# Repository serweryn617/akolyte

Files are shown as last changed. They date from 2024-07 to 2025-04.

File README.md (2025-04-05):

# Akolyte

⌨️ Low profile mechanical split keyboard

---

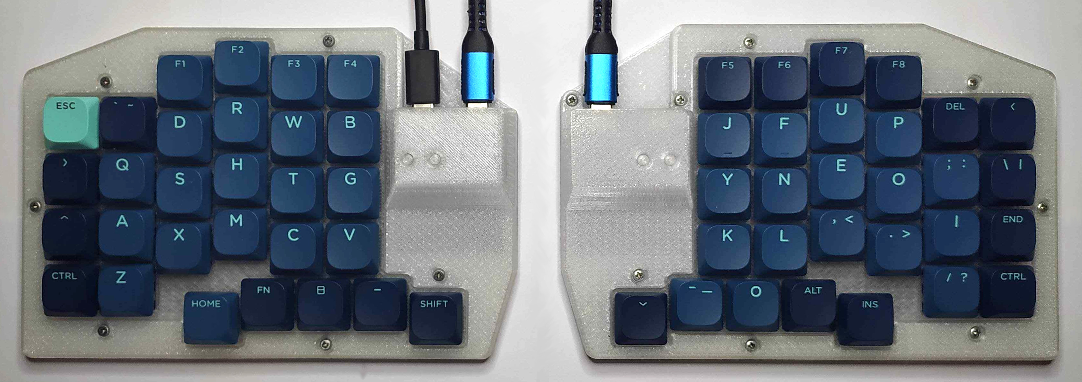
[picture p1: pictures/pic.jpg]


## Building firmware

Prerequisites:
 - `docker`

Firmware can be built using [cook-builder](https://github.com/serweryn617/cook):

**Setup:** initialize submodules and build Docker image. Has to be run only once:

```bash
cook setup
```

**Build:** build everything. Output files will be copied to the `output` directory:

```bash
cook
```

For complete list of commands run `cook -i`.

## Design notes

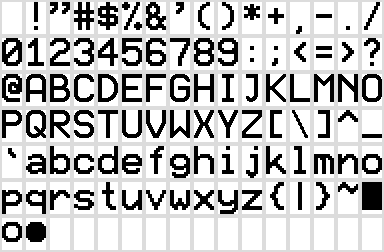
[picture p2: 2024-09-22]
firmware/helpers/chars_32.png

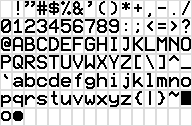
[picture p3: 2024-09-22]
firmware/helpers/chars_16.png

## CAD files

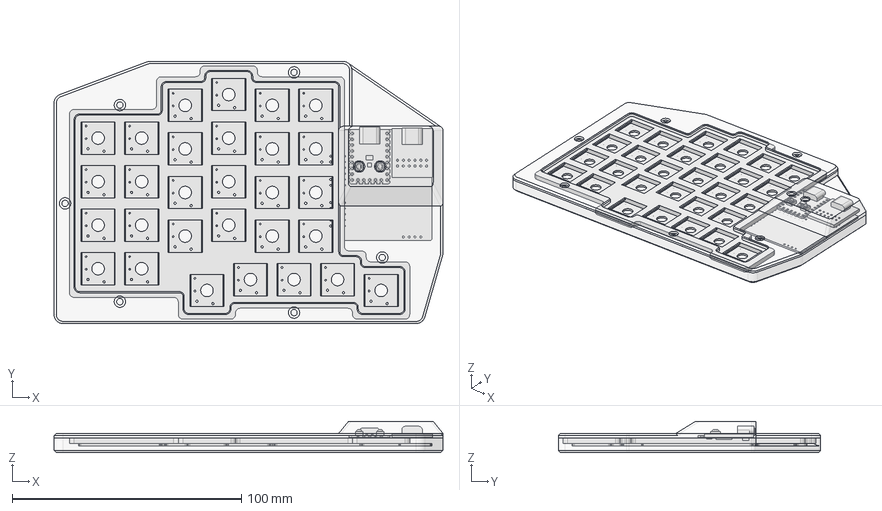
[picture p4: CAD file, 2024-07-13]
cad/freecad/assembly.FCStd
169.8 x 114.5 x 13.6 mm
pcb_left_001
bottom_001
plate_001
rp_001
usbc_001
top_001

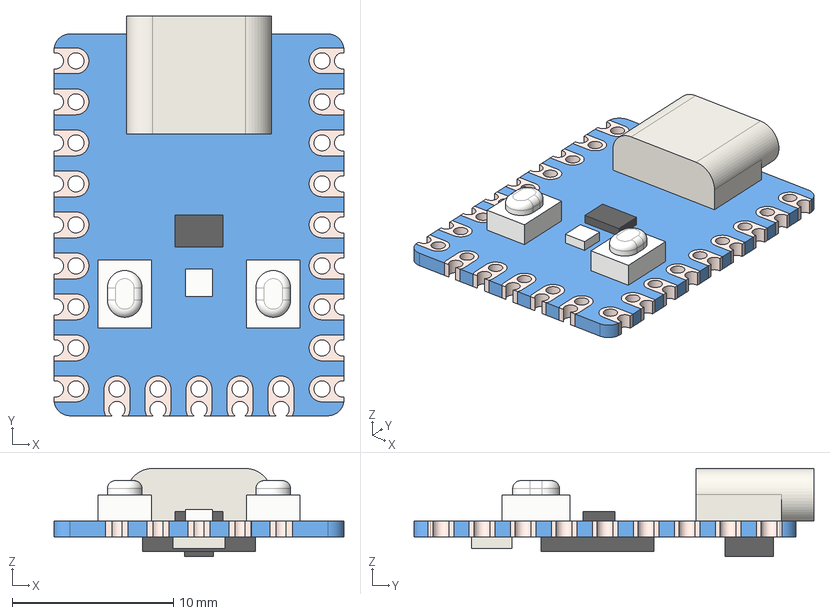
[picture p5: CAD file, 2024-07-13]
cad/freecad/components/rp.FCStd
18.0 x 24.8 x 5.45 mm
RP v1
RP v002
RP v003
RP v004
RP v005
RP v006
RP v007
RP v008
RP v009
RP v010
RP v011
RP v012
RP v013
RP v014
RP v015
RP v016
RP v017
RP v018
RP v019
RP v020
RP v021
RP v022
RP v023
RP v024
RP v025
RP v026
RP v027
RP v028
RP v029
RP v030
RP v031
RP v032

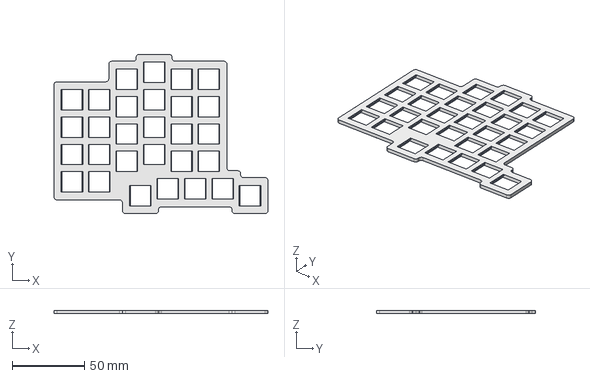
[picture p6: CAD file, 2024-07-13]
cad/freecad/plate.FCStd
148.5 x 110.5 x 2.40 mm

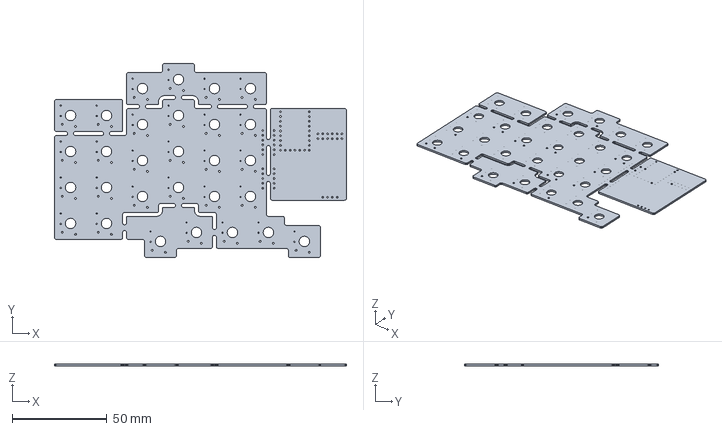
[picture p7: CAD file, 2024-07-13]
cad/freecad/components/pcb_left.FCStd
154.2 x 102.5 x 1.00 mm

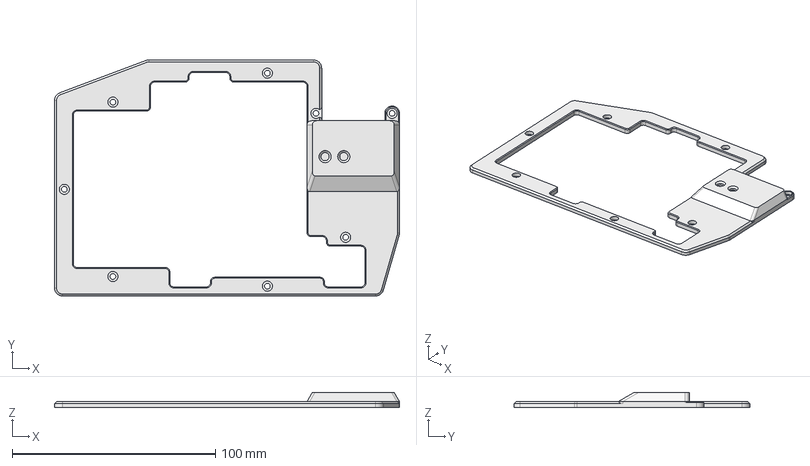
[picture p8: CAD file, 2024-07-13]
cad/freecad/top.FCStd
169.8 x 116.2 x 7.50 mm

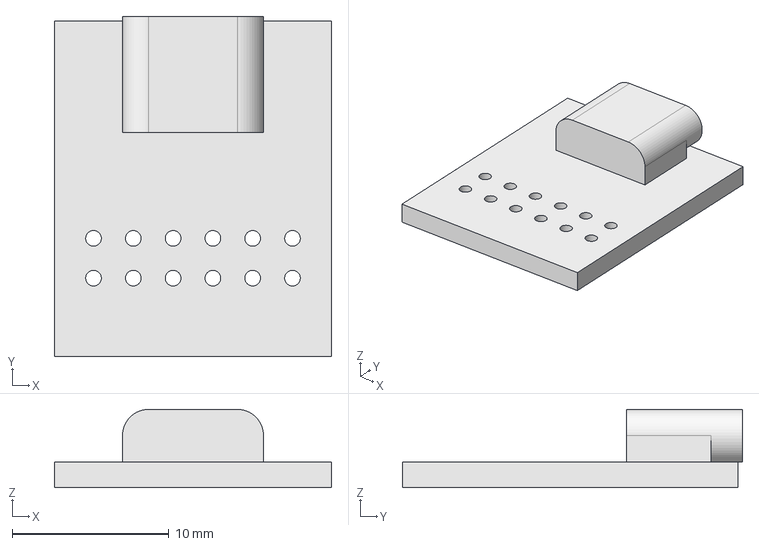
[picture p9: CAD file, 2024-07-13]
cad/freecad/components/usbc.FCStd
17.7 x 21.7 x 5.00 mm

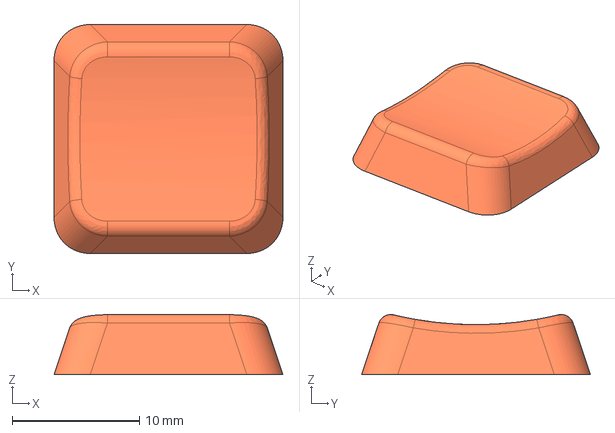
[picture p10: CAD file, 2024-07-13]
cad/freecad/components/keycap.FCStd
18.0 x 18.0 x 4.72 mm

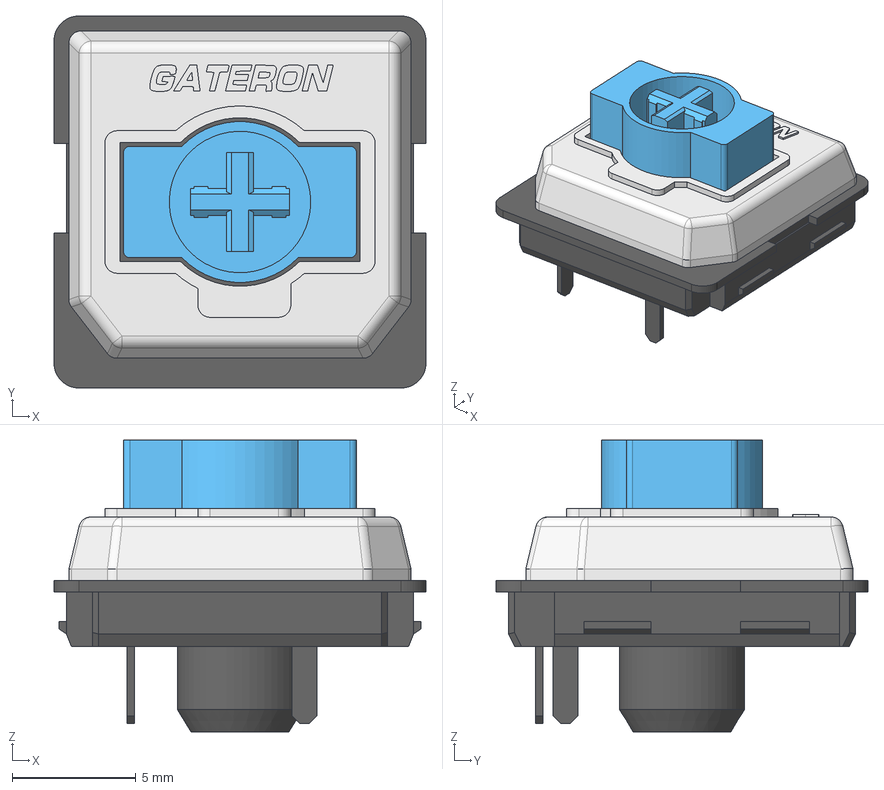
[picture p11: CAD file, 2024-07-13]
cad/freecad/components/gateron.FCStd
15.0 x 15.0 x 11.8 mm
GATERON Low Profile v2
GATERON Low Profile v003
GATERON Low Profile v004

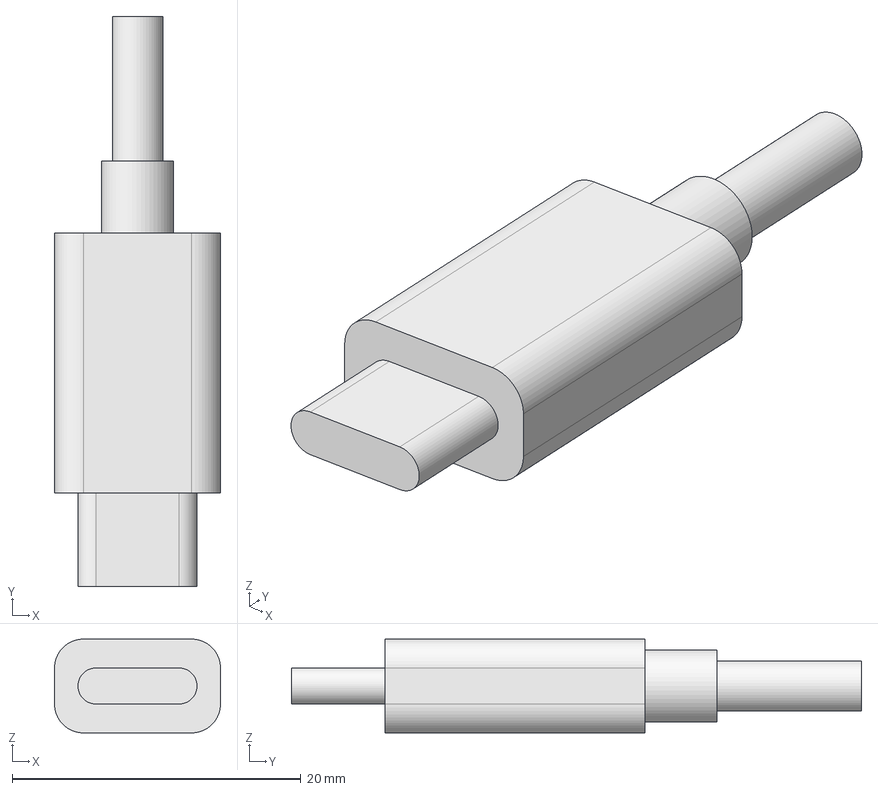
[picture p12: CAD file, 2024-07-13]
cad/freecad/components/usb-plug.FCStd
11.5 x 39.5 x 6.50 mm

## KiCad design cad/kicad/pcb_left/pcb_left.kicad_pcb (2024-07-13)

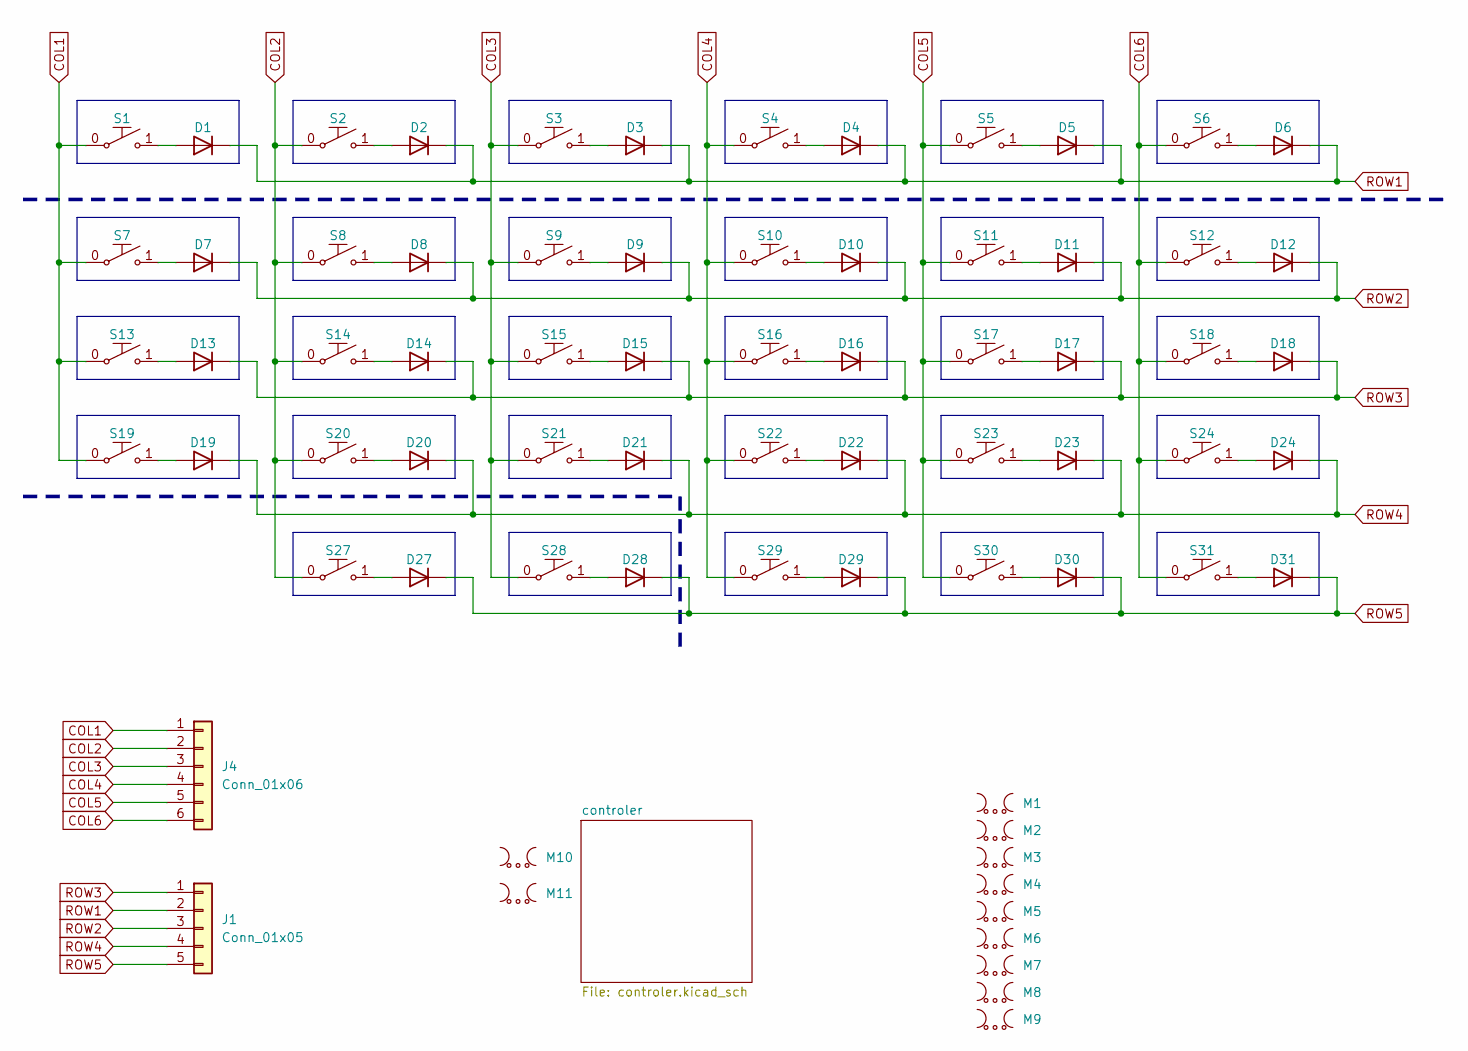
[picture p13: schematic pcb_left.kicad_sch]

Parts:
D1, D2, D3, D4, D5, D6, D7, D8, D9, D10, D11, D12, D13, D14, D15, D16, D17, D18, D19, D20, D21, D22, D23, D24, D27, D28, D29, D30, D31: 1N4148; SOD80_P5.5mm_Horizontal_SMD
J1: Conn_01x05; Row Connector
J4: Conn_01x06; Column Connector
M1, M2, M3, M4, M5, M6, M7, M8, M9, M10, M11: Mouse Bites
S1, S2, S3, S4, S5, S6, S7, S8, S9, S10, S11, S12, S13, S14, S15, S16, S17, S18, S19, S20, S21, S22, S23, S24, S27, S28, S29, S30, S31: Gateron_Switch; GATERON

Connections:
COL1: J4.1, S1.0, S7.0, S13.0, S19.0; also elsewhere on the board
COL2: J4.2, S2.0, S8.0, S14.0, S20.0, S27.0; also elsewhere on the board
COL3: J4.3, S3.0, S9.0, S15.0, S21.0, S28.0; also elsewhere on the board
COL4: J4.4, S4.0, S10.0, S16.0, S22.0, S29.0; also elsewhere on the board
COL5: J4.5, S5.0, S11.0, S17.0, S23.0, S30.0; also elsewhere on the board
COL6: J4.6, S6.0, S12.0, S18.0, S24.0, S31.0; also elsewhere on the board
unnamed: D1.2 (A), S1.1
unnamed: D2.2 (A), S2.1
unnamed: D3.2 (A), S3.1
unnamed: D4.2 (A), S4.1
unnamed: D5.2 (A), S5.1
unnamed: D6.2 (A), S6.1
unnamed: D7.2 (A), S7.1
unnamed: D8.2 (A), S8.1
unnamed: D9.2 (A), S9.1
unnamed: D10.2 (A), S10.1
unnamed: D11.2 (A), S11.1
unnamed: D12.2 (A), S12.1
unnamed: D13.2 (A), S13.1
unnamed: D14.2 (A), S14.1
unnamed: D15.2 (A), S15.1
unnamed: D16.2 (A), S16.1
unnamed: D17.2 (A), S17.1
unnamed: D18.2 (A), S18.1
unnamed: D19.2 (A), S19.1
unnamed: D20.2 (A), S20.1
unnamed: D21.2 (A), S21.1
unnamed: D22.2 (A), S22.1
unnamed: D23.2 (A), S23.1
unnamed: D24.2 (A), S24.1
unnamed: D27.2 (A), S27.1
unnamed: D28.2 (A), S28.1
unnamed: D29.2 (A), S29.1
unnamed: D30.2 (A), S30.1
unnamed: D31.2 (A), S31.1
ROW1: D1.1 (K), D2.1 (K), D3.1 (K), D4.1 (K), D5.1 (K), D6.1 (K), J1.2; also elsewhere on the board
ROW2: D7.1 (K), D8.1 (K), D9.1 (K), D10.1 (K), D11.1 (K), D12.1 (K), J1.3; also elsewhere on the board
ROW3: D13.1 (K), D14.1 (K), D15.1 (K), D16.1 (K), D17.1 (K), D18.1 (K), J1.1; also elsewhere on the board
ROW4: D19.1 (K), D20.1 (K), D21.1 (K), D22.1 (K), D23.1 (K), D24.1 (K), J1.4; also elsewhere on the board
ROW5: D27.1 (K), D28.1 (K), D29.1 (K), D30.1 (K), D31.1 (K), J1.5; also elsewhere on the board

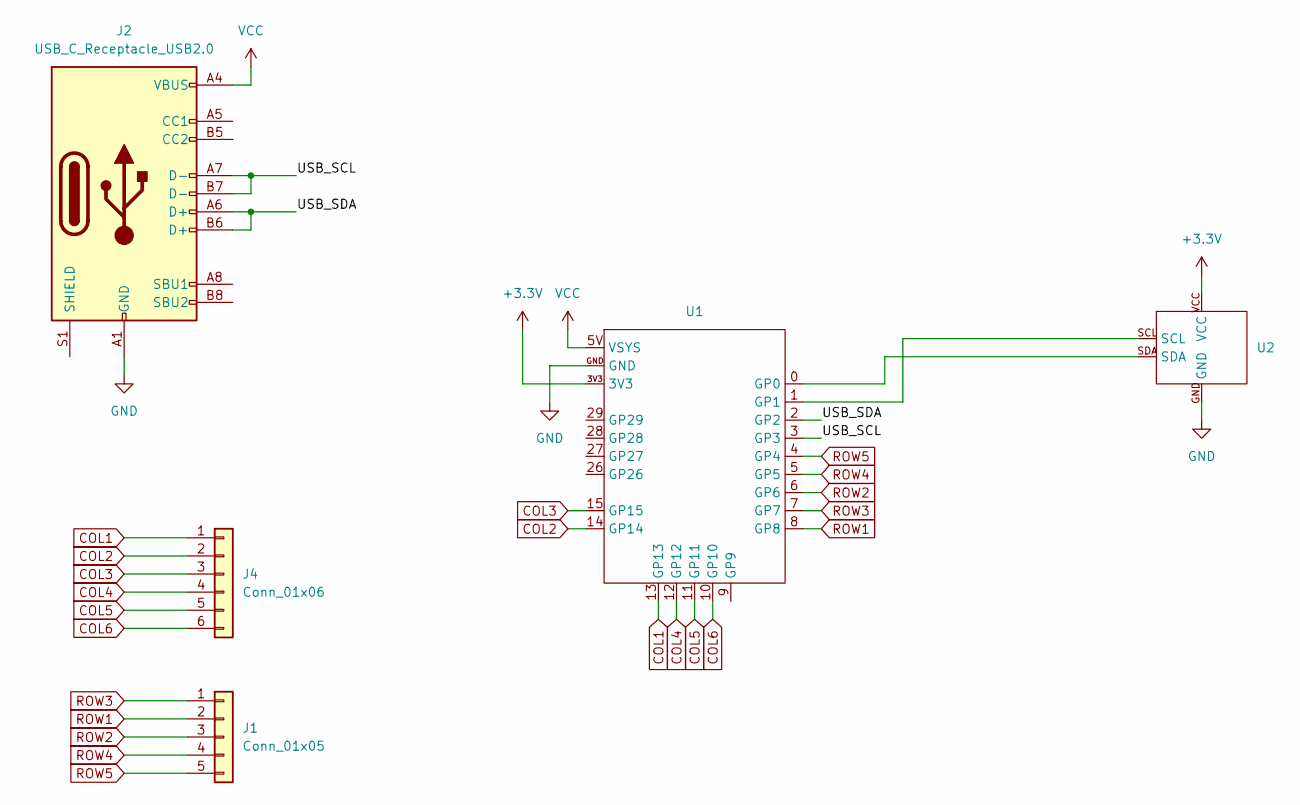
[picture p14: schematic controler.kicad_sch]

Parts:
J1: Conn_01x05; Row Connector
J2: USB_C_Receptacle_USB2.0; USB C Port
J4: Conn_01x06; Column Connector
U1: RP2040 - Zero
U2: OLED

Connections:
+3.3V: U1.3V3, U2.VCC
/controler/USB_SCL: J2.A7 (D-), J2.B7 (D-), U1.3 (GP3)
/controler/USB_SDA: J2.A6 (D+), J2.B6 (D+), U1.2 (GP2)
COL1: J4.1, U1.13 (GP13); also elsewhere on the board
COL2: J4.2, U1.14 (GP14); also elsewhere on the board
COL3: J4.3, U1.15 (GP15); also elsewhere on the board
COL4: J4.4, U1.12 (GP12); also elsewhere on the board
COL5: J4.5, U1.11 (GP11); also elsewhere on the board
COL6: J4.6, U1.10 (GP10); also elsewhere on the board
GND: J2.A1 (GND), J2.A12 (GND), J2.B1 (GND), J2.B12 (GND), U1.GND, U2.GND
unnamed: U1.0 (GP0), U2.SDA
unnamed: U1.1 (GP1), U2.SCL
ROW1: J1.2, U1.8 (GP8); also elsewhere on the board
ROW2: J1.3, U1.6 (GP6); also elsewhere on the board
ROW3: J1.1, U1.7 (GP7); also elsewhere on the board
ROW4: J1.4, U1.5 (GP5); also elsewhere on the board
ROW5: J1.5, U1.4 (GP4); also elsewhere on the board
VCC: J2.A4 (VBUS), J2.A9 (VBUS), J2.B4 (VBUS), J2.B9 (VBUS), U1.5V (VSYS)

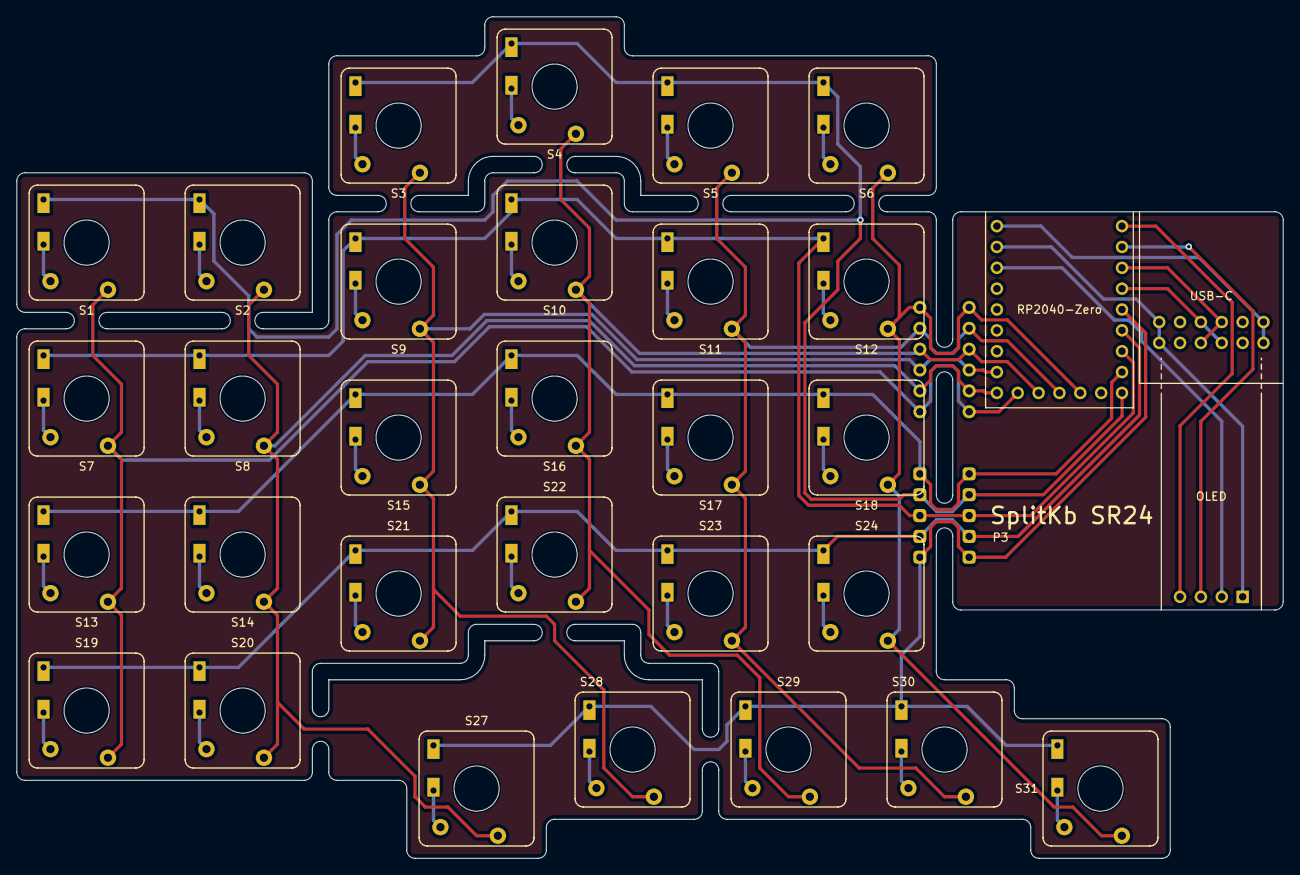
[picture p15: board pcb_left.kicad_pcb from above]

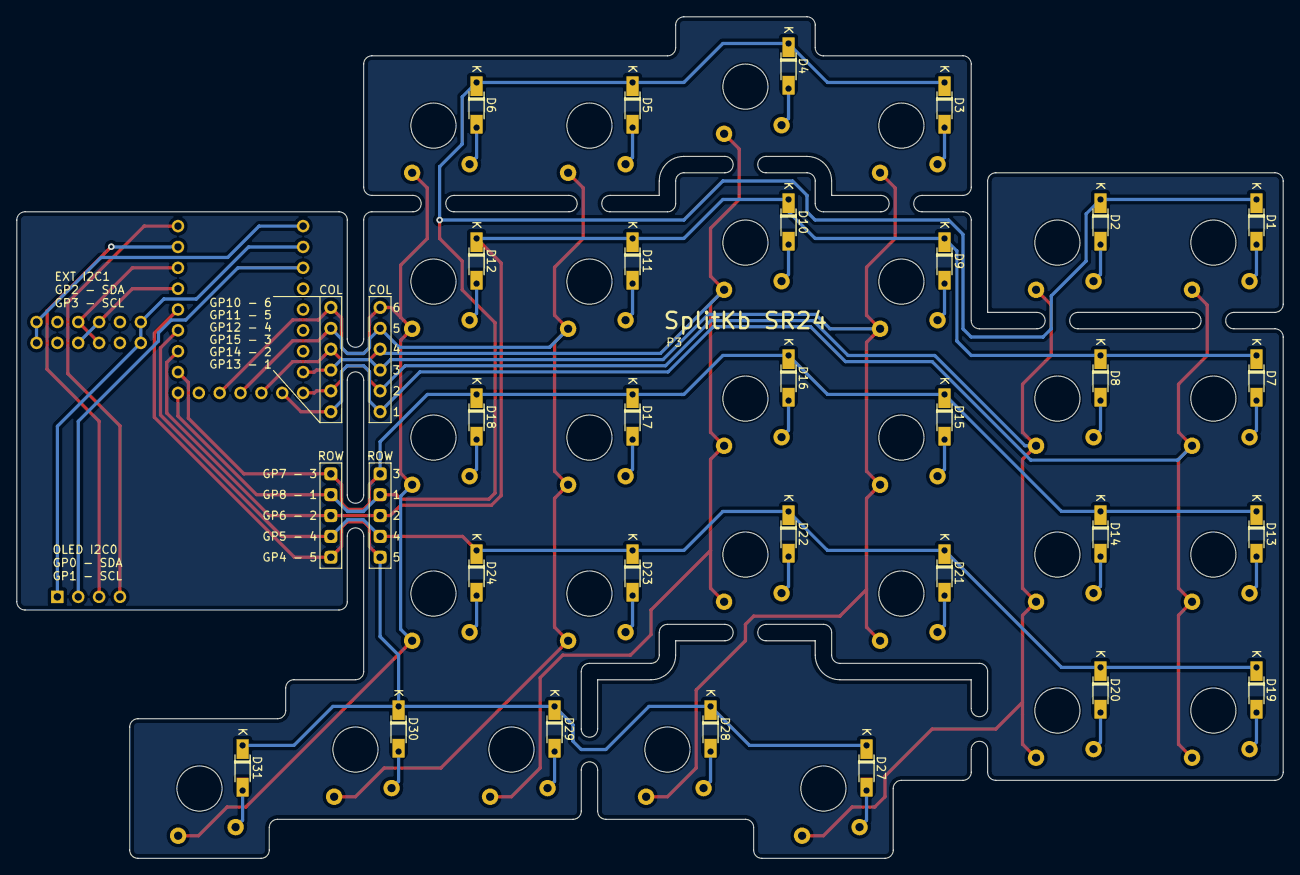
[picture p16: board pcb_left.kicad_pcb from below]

Board: 2 copper layers, 154.2 x 102.5 mm, 76 parts (33 on the bottom side), 47 nets.

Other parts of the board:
J5: Conn_01x06; Column Connector
J6: Conn_01x05; Row Connector

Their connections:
COL1: J5.1; also elsewhere on the board
COL2: J5.2; also elsewhere on the board
COL3: J5.3; also elsewhere on the board
COL4: J5.4; also elsewhere on the board
COL5: J5.5; also elsewhere on the board
COL6: J5.6; also elsewhere on the board
ROW1: J6.2; also elsewhere on the board
ROW2: J6.3; also elsewhere on the board
ROW3: J6.1; also elsewhere on the board
ROW4: J6.4; also elsewhere on the board
ROW5: J6.5; also elsewhere on the board

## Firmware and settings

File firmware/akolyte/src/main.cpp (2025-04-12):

#include "pico/multicore.h"

#include "akolyte/core1.hpp"
#include "akolyte/flow_selector.hpp"
#include "akolyte/i2c_worker.hpp"
#include "akolyte/usb_manager.hpp"
#include "communication/communication.hpp"
#include "defs/defs.hpp"
#include "i2c/i2c_driver.h"
#include "keypad/keypad.hpp"
#include "queue/queue.hpp"
#include "tinyusb.hpp"
#include "types.h"

using namespace drivers::i2c;
using namespace lib::communication;
using namespace lib::keypad;
using namespace lib::queue;

tinyusb_callback global_tinyusb_callback {
    .complete = true,
    .leds = 0,
    .mounted = false,
    .suspended = false,
};

int main()
{
    Queue queue;
    queue.initialize();

    TinyUSB t_usb(global_tinyusb_callback);
    I2CDriver i2c_driver(i2c1, ext_i2c_sda, ext_i2c_scl, 0x55);
    communication comms(i2c_driver);

    Keypad keypad(keypad_in_pins, keypad_out_pins);
    usb_manager manager(t_usb, comms, global_tinyusb_callback, keypad, queue);
    i2c_worker worker(comms, keypad, queue);
    flow_selector selector(t_usb, comms, global_tinyusb_callback, manager, worker);

    if constexpr (config::side == config::left) {
        multicore_launch_core1(core1_main);
    }

    keypad.init_gpio();
    selector.init_all();
    selector.start();
}

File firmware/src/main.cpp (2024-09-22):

#include <stdio.h>

#include "pico/stdlib.h"
#include "pico/multicore.h"
#include "pico/util/queue.h"

#include "pico_i2c_driver.h"
#include "defs.hpp"
#include "keypad.hpp"
#include "led.hpp"
#include "tinyusb.hpp"
#include "types.h"
#include "flow_selector.hpp"
#include "usb_manager.hpp"
#include "i2c_worker.hpp"
#include "logger.hpp"
#include "ssd1306.h"

tinyusb_callback g_tinyusb_callback {
    .complete = true,
    .leds = 0,
    .mounted = false,
    .suspended = false,
};

queue_t inter_core_queue;

void core1_main()
{
    drivers::pico::PicoI2CDriver i2c_driver(oled_i2c, oled_i2c_sda, oled_i2c_scl, oled_i2c_address);
    i2c_driver.init();

    ssd1306 oled(i2c_driver);
    oled.init();

    uint8_t last_message = 0;

    while(true) {
        oled.set_cursor(0, 0);
        switch (last_message) {
            case 0:
                oled.print_string("None");
                break;
            case 1:
                oled.print_string("Running primary");
                break;
            case 2:
                oled.print_string("Running secondary");
                break;
            default:
                oled.print_string("ERROR");
                break;
        }
        oled.display();
        queue_remove_blocking(&inter_core_queue, &last_message);
    }
}

int main()
{
    queue_init(&inter_core_queue, sizeof(uint8_t), 16);
    multicore_launch_core1(core1_main);

    Logger log;
    log.set_on(true);

    TinyUSB t_usb(g_tinyusb_callback);
    drivers::pico::PicoI2CDriver i2c_driver(i2c1, ext_i2c_sda, ext_i2c_scl, 0x55);
    Led led(led_builtin);
    Keypad keypad;

    keypad.init_gpio();

    usb_manager manager(t_usb, i2c_driver, led, g_tinyusb_callback, keypad, log);
    i2c_worker worker(i2c_driver, keypad, led);

    flow_selector selector(t_usb, i2c_driver, inter_core_queue, led, g_tinyusb_callback, manager, worker, log);

    log.print("Starting\r\n");

    selector.init_all();
    selector.start();
}

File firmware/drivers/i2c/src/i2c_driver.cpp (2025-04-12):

#include "i2c/i2c_driver.h"
#include "pico/i2c_slave.h"

namespace drivers::i2c {

static constexpr unsigned command_buffer_size = 16;

volatile static bool to_send = 0;
volatile static bool to_receive = 0;

static struct {
    uint8_t state[4] = {};

    uint8_t command[command_buffer_size] = {};
    uint8_t command_size = 0;
    bool command_ready = false;
} global_context;

void i2c_slave_handler(i2c_inst_t *i2c, i2c_slave_event_t event) {
    switch (event) {
    case I2C_SLAVE_RECEIVE:
        to_receive = true;

        if (global_context.command_ready == true) {
            global_context.command_ready = false;
            global_context.command_size = 0;
        }

        if (global_context.command_size < command_buffer_size) {
            global_context.command[global_context.command_size++] = i2c_read_byte_raw(i2c);
        }

        break;
    case I2C_SLAVE_REQUEST:
        to_send = true;
        break;
    case I2C_SLAVE_FINISH:
        global_context.command_ready = true;
        break;
    default:
        break;
    }
}

I2CDriver::I2CDriver(i2c_inst_t *i2c_inst, uint8_t pin_sda, uint8_t pin_scl, uint8_t i2c_address)
    : i2c_inst_(i2c_inst)
    , i2c_address_(i2c_address)
    , pin_sda_(pin_sda)
    , pin_scl_(pin_scl)
{
}

void I2CDriver::init()
{
    i2c_init(i2c_inst_, 200 * 1000);
    gpio_set_function(pin_sda_, GPIO_FUNC_I2C);
    gpio_set_function(pin_scl_, GPIO_FUNC_I2C);
    gpio_pull_up(pin_sda_);
    gpio_pull_up(pin_scl_);
}

int I2CDriver::read_data(uint8_t *buffer, uint32_t length, uint32_t timeout)
{
    if (timeout) {
        return i2c_read_timeout_us(i2c_inst_, i2c_address_, buffer, length, false, timeout);
    } else {
        return i2c_read_blocking(i2c_inst_, i2c_address_, buffer, length, false);
    }
}

int I2CDriver::write_data(const uint8_t *buffer, uint32_t length, uint32_t timeout)
{
    if (timeout) {
        return i2c_write_timeout_us(i2c_inst_, i2c_address_, buffer, length, false, timeout);
    } else {
        return i2c_write_blocking(i2c_inst_, i2c_address_, buffer, length, false);
    }
}

bool I2CDriver::slave_requested()
{
    return to_send;
}

void I2CDriver::clear_slave_request()
{
    to_send = 0;
}

void I2CDriver::slave_write_byte(uint8_t byte)
{
    return i2c_write_byte_raw(i2c_inst_, byte);
}

bool I2CDriver::slave_received()
{
    bool temp = to_receive;
    to_receive = 0;
    return temp;
}

uint8_t I2CDriver::slave_read_byte()
{
    return i2c_read_byte_raw(i2c_inst_);
}

void I2CDriver::set_slave_mode(bool slave)
{
    if (slave) {
        i2c_slave_init(i2c_inst_, i2c_address_, &i2c_slave_handler);
    } else {
        i2c_slave_deinit(i2c_inst_);
    }
}

uint8_t* I2CDriver::get_command_address() {
    return global_context.command;
}

uint8_t I2CDriver::get_command_size() {
    if (global_context.command_ready) {
        uint8_t tmp_size = global_context.command_size;

        global_context.command_ready = false;
        global_context.command_size = 0;

        return tmp_size;
    }

    return 0;
}

}  // namespace drivers::i2c

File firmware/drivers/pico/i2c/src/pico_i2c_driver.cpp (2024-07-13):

#include "../inc/pico_i2c_driver.h"
#include "pico/i2c_slave.h"

namespace drivers::pico {

volatile static bool to_send = 0;
volatile static bool to_receive = 0;

void i2c_slave_handler(i2c_inst_t *i2c, i2c_slave_event_t event) {
    switch (event) {
    case I2C_SLAVE_RECEIVE:
        to_receive = true;
        i2c_read_byte_raw(i2c);
        break;
    case I2C_SLAVE_REQUEST:
        to_send = true;
        break;
    default:
        break;
    }
}

PicoI2CDriver::PicoI2CDriver(i2c_inst_t *i2c_inst, uint8_t pin_sda, uint8_t pin_scl, uint8_t i2c_address)
    : i2c_inst_(i2c_inst)
    , i2c_address_(i2c_address)
    , pin_sda_(pin_sda)
    , pin_scl_(pin_scl)
{
}

void PicoI2CDriver::init()
{
    i2c_init(i2c_inst_, 200 * 1000);
    gpio_set_function(pin_sda_, GPIO_FUNC_I2C);
    gpio_set_function(pin_scl_, GPIO_FUNC_I2C);
    gpio_pull_up(pin_sda_);
    gpio_pull_up(pin_scl_);
}

int PicoI2CDriver::read_data(uint8_t *buffer, uint8_t length, uint32_t timeout)
{
    if (timeout) {
        return i2c_read_timeout_us(i2c_inst_, i2c_address_, buffer, length, false, timeout);
    } else {
        return i2c_read_blocking(i2c_inst_, i2c_address_, buffer, length, false);
    }
}

int PicoI2CDriver::write_data(const uint8_t *buffer, uint8_t length, uint32_t timeout)
{
    if (timeout) {
        return i2c_write_timeout_us(i2c_inst_, i2c_address_, buffer, length, false, timeout);
    } else {
        return i2c_write_blocking(i2c_inst_, i2c_address_, buffer, length, false);
    }
}

bool PicoI2CDriver::slave_requested()
{
    return to_send;
}

void PicoI2CDriver::clear_slave_request()
{
    to_send = 0;
}

void PicoI2CDriver::slave_write_byte(uint8_t byte)
{
    return i2c_write_byte_raw(i2c_inst_, byte);
}

bool PicoI2CDriver::slave_received()
{
    bool temp = to_receive;
    to_receive = 0;
    return temp;
}

uint8_t PicoI2CDriver::slave_get_byte()
{
    return i2c_read_byte_raw(i2c_inst_);
}

void PicoI2CDriver::set_slave_mode(bool slave)
{
    if (slave) {
        i2c_slave_init(i2c_inst_, i2c_address_, &i2c_slave_handler);
    } else {
        i2c_slave_deinit(i2c_inst_);
    }
}

}  // namespace drivers::pico

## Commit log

2024-07-16 Add Pico SDK submodule
2024-09-18 Oled support (#2)
    * Update recipe for new cook version
    * Initial OLED driver
    * Use I2C driver
    * Update max data length
    * oled working
2024-11-09 Add base layout switching
2025-03-23 I2C Commands WIP
2025-03-23 Update Pico SDK
2025-03-24 I2C slave commands WIP
2025-03-25 Add variable payload length and crc to I2C commands
2025-04-02 Add UART
2025-04-03 Led indicators
2025-04-12 I2c info (#5)
    * Send OLED info over I2C
    * Reduce I2C speed
    * Remove leftovers
    * Fix rare OLED core blocking
    * Rename member
    [flow_selector.cpp, i2c_driver.cpp, i2c_worker.cpp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]
2025-09-13 I2c info (#6)
    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
